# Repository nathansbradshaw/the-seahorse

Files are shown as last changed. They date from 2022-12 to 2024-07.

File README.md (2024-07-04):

# The Seahorse v2 

34 key keyboard with TP

Link to ZMK code https://github.com/nathansbradshaw/zmk-the-seahorse
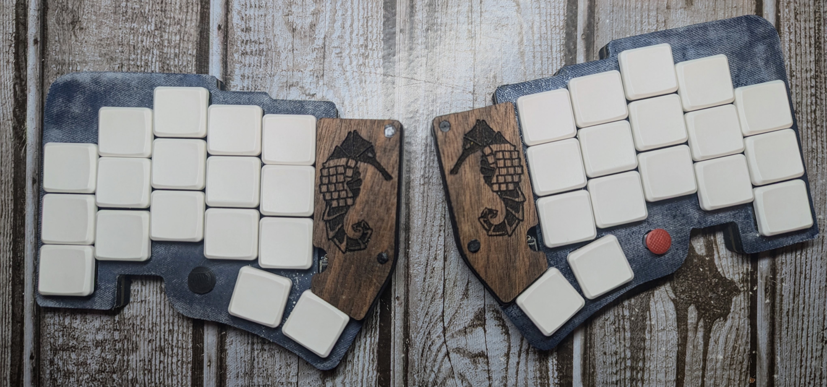
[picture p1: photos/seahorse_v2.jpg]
the-seahorse board


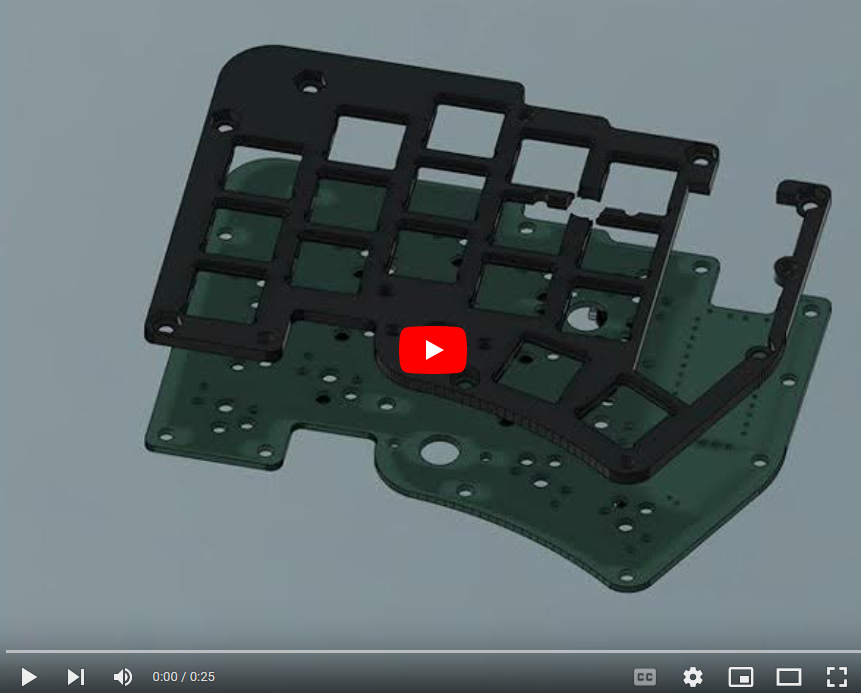
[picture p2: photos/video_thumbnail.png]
IMAGE ALT TEXT (https://www.youtube.com/watch?v=ttfX7KnK4Xc "Video Title")


# BOM
These are links to what I bought, not necessary to get exactly the same

## items
- 4x (12 socket) [2.54mm Sockets (Cheap) - Recommended](https://www.amazon.com/gp/product/B0778TFL39/ref=ppx_yo_dt_b_search_asin_image?ie=UTF8&psc=1) or  [2.54mm Sockets (Quality)](https://www.mouser.com/ProductDetail/Mill-Max/315-43-112-41-003000?qs=s8Nb1z4Wn%2FRfWrVqQ0TOuQ%3D%3D)

- 48x [Mill Max Pins - Recommend (Digikey)](https://www.digikey.com/en/products/detail/3320-0-00-15-00-00-03-0/4147392)

- 34x [Choc Hot Swap Sockets](https://www.boardsource.xyz/products/Choc_Hot_Swap_Sockets)

- 34x Choc Switches

- 34x Choc Key caps

- 2x Nice!Nano or equivalent

- 34x [1N4148W-7-F - Diodes](https://www.digikey.com/en/products/detail/diodes-incorporated/1N4148W-7-F/814371)

- 2x [SSSS811101 - Battery Switch](https://www.digikey.com/en/products/detail/alps-alpine/SSSS811101/19529062?s=N4IgTCBcDaIMoLgDgIxoAwpAXQL5A)

- 2x [PTS636 SL43 LFS - Reset Switch](https://www.digikey.com/en/products/detail/c-k/PTS636-SL43-LFS/10071714)

- 2x [Lithium Battery 110mAh](https://typeractive.xyz/products/lithium-battery-110mah)

- 2x [JST Battery Jack](https://typeractive.xyz/products/battery-jack)

- 1x [T460s - Track Point (12 pin RED version)]()

- 1x [2005280120 - 12 pin 1.0mm Pitch (Note: Link might be wrong)](https://www.digikey.com/en/products/detail/molex/2005280120/12142065?s=N4IgTCBcDa4AxwKxgBwFo4EYxwAQgF0BfIA)

- 2x 1.8m screw and nut

# Estimated Cost to build (Updated July 3, 2024)

|Amount| | Item | Cost |Salvageable|
|----|---|---|---|---|
| 2  | | Reset Switch | $0.20 USD | No  |
| 2  | | Nice!Nano | $50.00 USD  | Yes |
| 2  | | Lithium Battery 110mAh  | $6.00 USD | Yes |
| 2  | | JST Battery Jack | $2.00 USD | No  |
| 2  | | Battery Switch | $2.50 | No  |
| 34 | | Choc Switches | $27.00 USD  | Yes |
| 34 | | Hot Swap Choc Sockets | $5.10 USD | No  |
| 34 | | Choc Key cap | $11.90 USD  | Yes |
| 34 | | Diodes | $5.44 USD | No  |
| 48 | | Mill Max Pins | $4.76 USD | yes-ish|
| 4  | | 2.54mm Sockets | $1.60 USD | No  |
| 1  | | PCB | $10.00 USD  | No  |
| 1  | | Track Point | $10.00 USD  | Yes |
| 1  | | FPC Cable | Free w/ TP  | Yes |
| 1  | | FPC connector | $2.00 USD | Yes |
 
-----

 Total Cost Without TP: **$121.74 USD**

 Total Cost With TP: **$133.77 USD**

---------

 Total Cost to upgrade: **$22.10 USD**

 Total Cost to upgrade with TP: **$24.10 USD**

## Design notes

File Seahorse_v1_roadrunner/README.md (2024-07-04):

# The Seahorse V1 or The RoadRunner
------
This keyboard design works well, but had a couple of issues. The main one was that the micro-controller is too close to the keys, which required the user to shave off some of the key caps to get it all to fit.

In other words, build at your own risk.

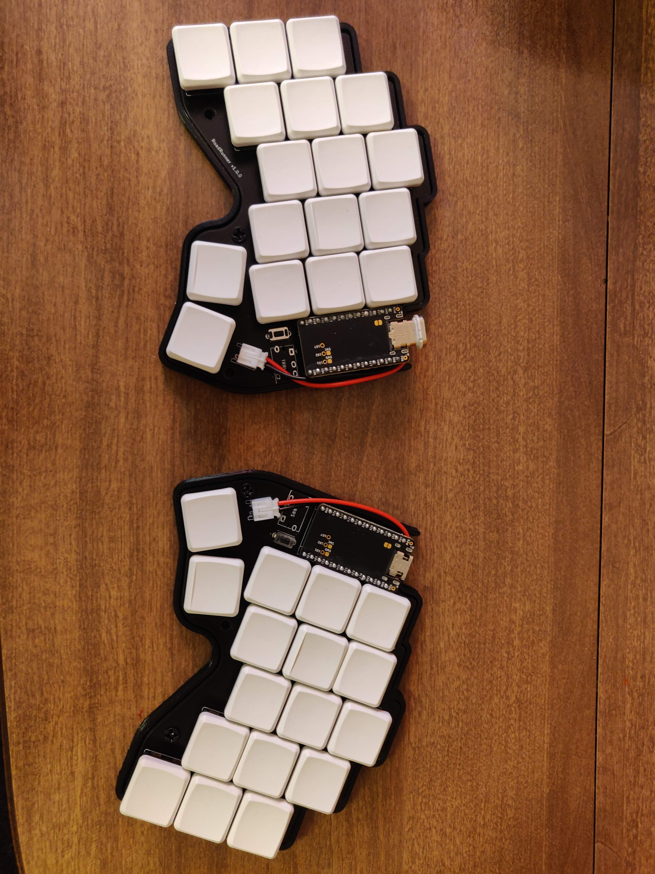
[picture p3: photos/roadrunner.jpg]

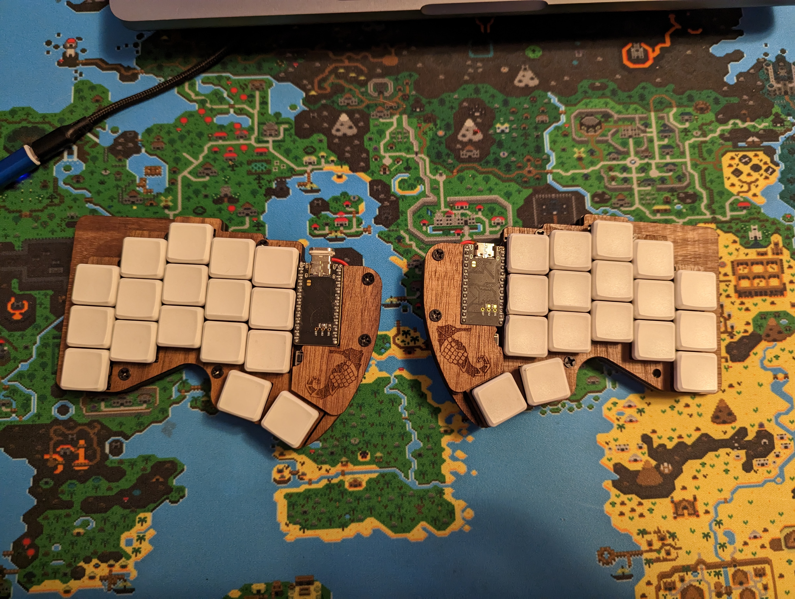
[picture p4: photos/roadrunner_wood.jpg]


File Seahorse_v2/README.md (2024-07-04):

# The Seahorse v2 

34 key keyboard with TP

Link to ZMK code https://github.com/nathansbradshaw/zmk-the-seahorse
the-seahorse board
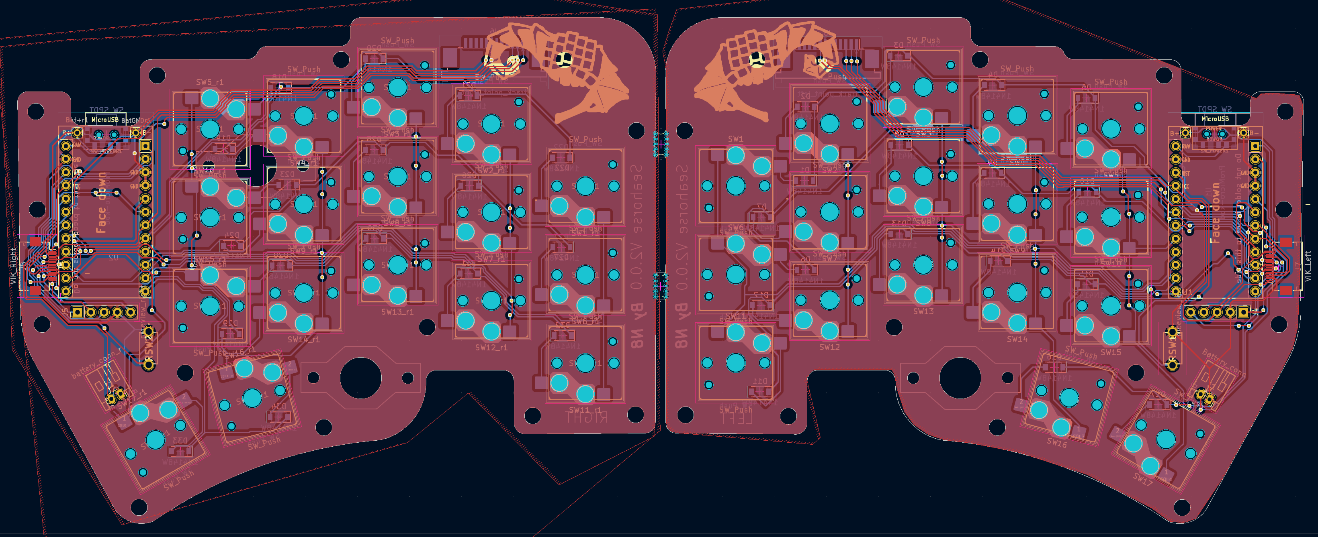
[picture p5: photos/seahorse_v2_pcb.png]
the-seahorse board

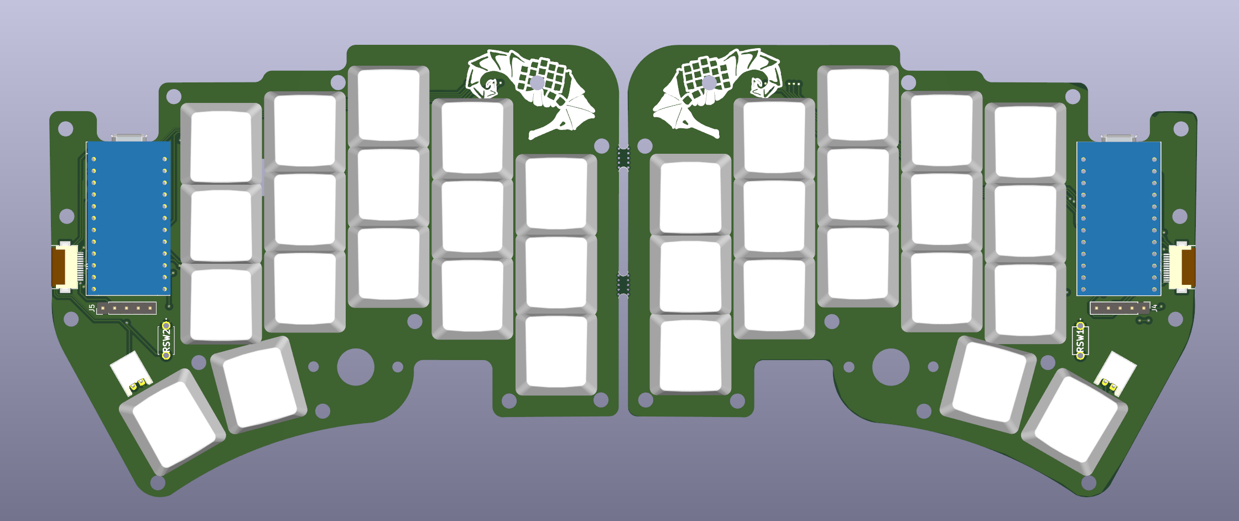
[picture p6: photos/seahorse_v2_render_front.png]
the-seahorse board

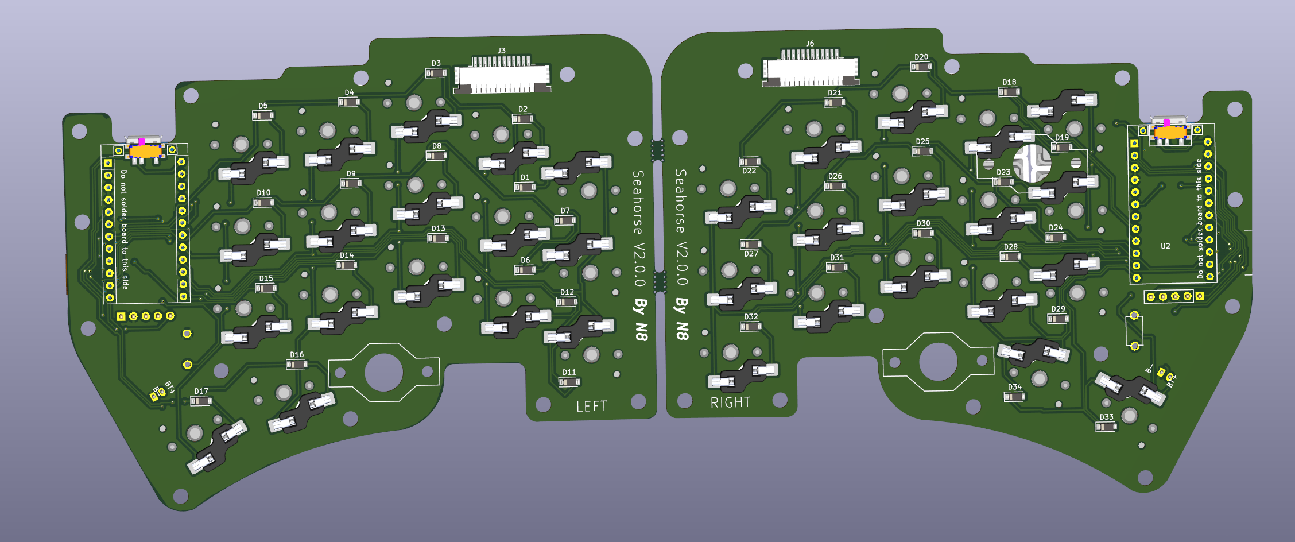
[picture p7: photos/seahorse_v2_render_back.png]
the-seahorse board


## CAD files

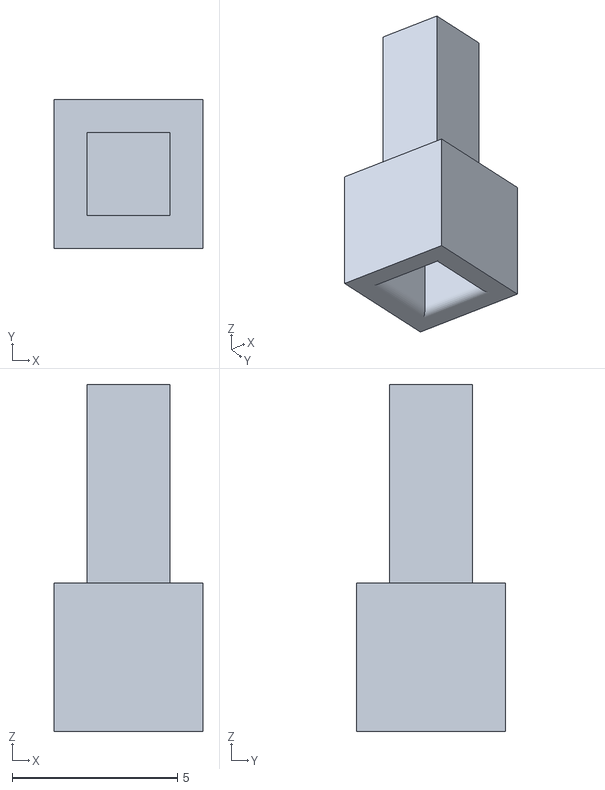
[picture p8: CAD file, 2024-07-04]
print_files/seahorse_v2_files/track_point_extender.stl
4.50 x 4.50 x 10.5

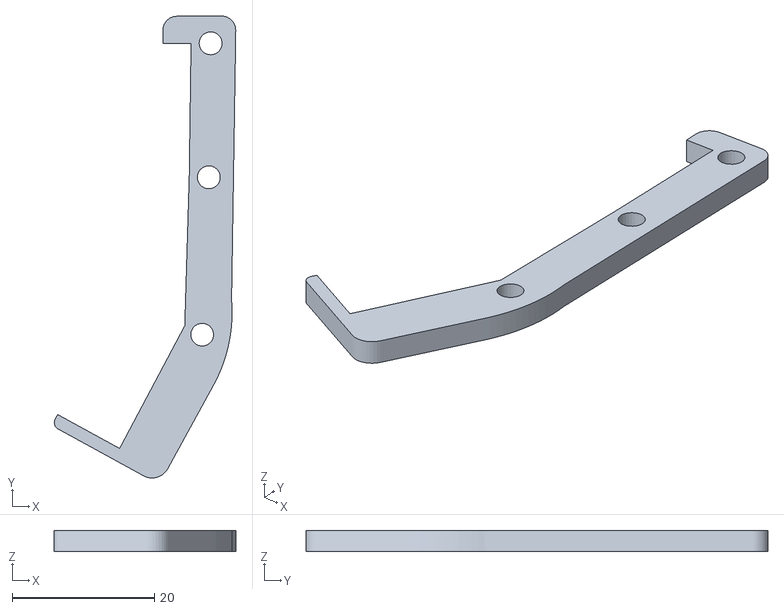
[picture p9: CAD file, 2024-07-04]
print_files/seahorse_v2_files/side_plate_spacer_thick.stl
25.5 x 64.9 x 2.95

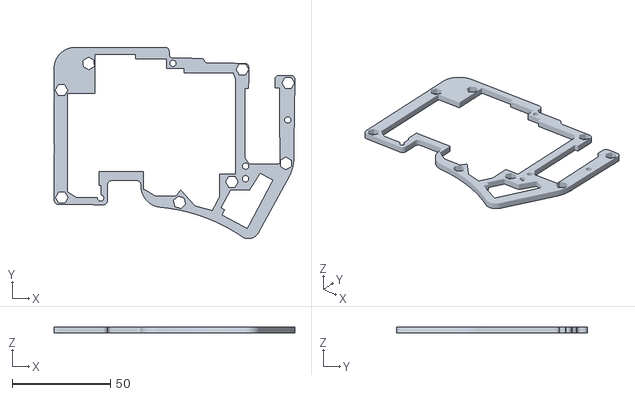
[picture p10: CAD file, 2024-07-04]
print_files/seahorse_v2_files/spacer_plate.stl
122.5 x 97.2 x 3.25

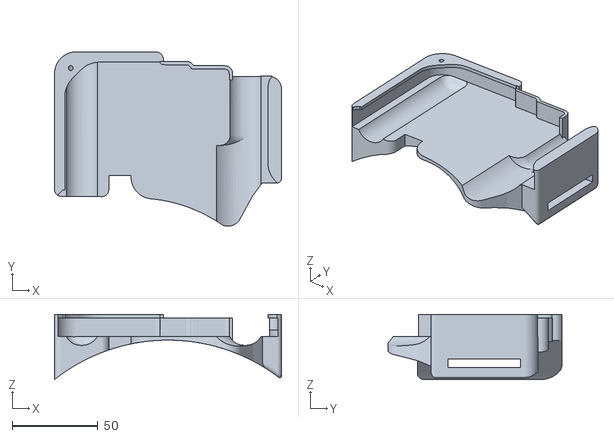
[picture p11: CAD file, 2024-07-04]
print_files/seahorse_v2_files/barnicle.stl
132.5 x 101.8 x 38.0

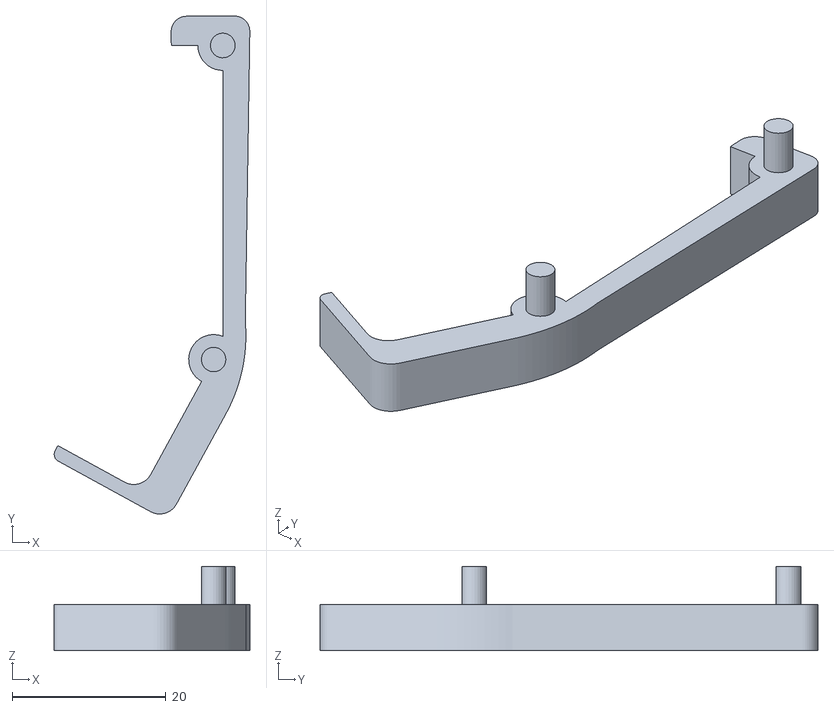
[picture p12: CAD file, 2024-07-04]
print_files/seahorse_v2_files/side_cover_spacer_with_pegs.stl
25.5 x 64.9 x 11.0

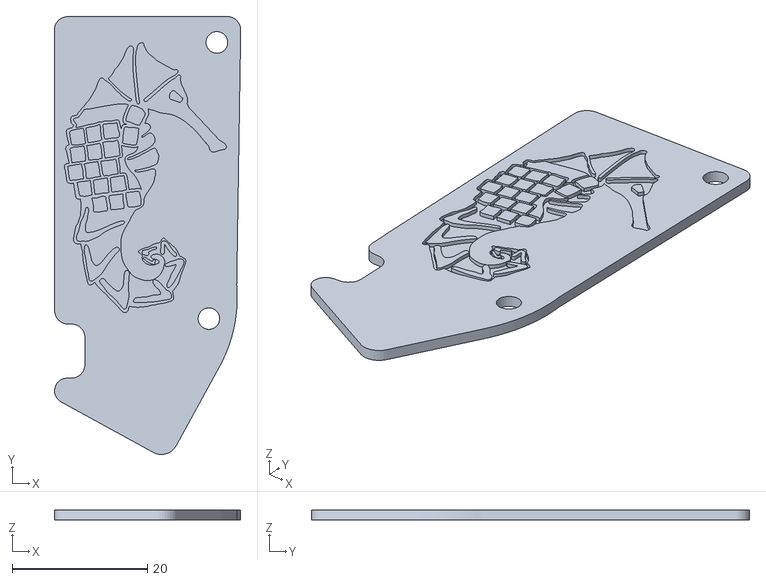
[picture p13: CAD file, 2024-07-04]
print_files/seahorse_v2_files/micro_controller_cover.stl
27.6 x 64.9 x 1.45

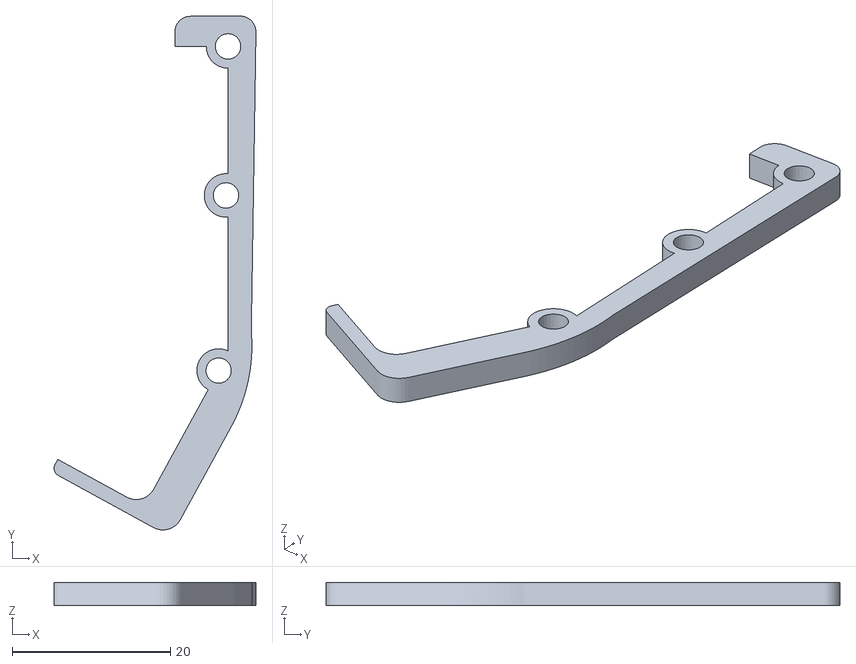
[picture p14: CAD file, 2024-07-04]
print_files/seahorse_v2_files/side_plate_spacer_slim.stl
25.5 x 64.9 x 2.95

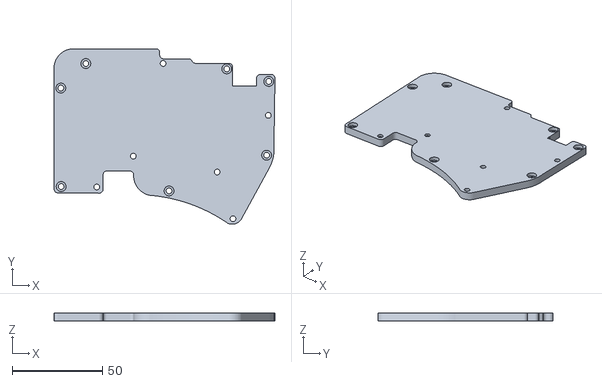
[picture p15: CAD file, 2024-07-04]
print_files/seahorse_v2_files/bottom_print_plate_counter_sink_screw.stl
122.5 x 97.2 x 4.50

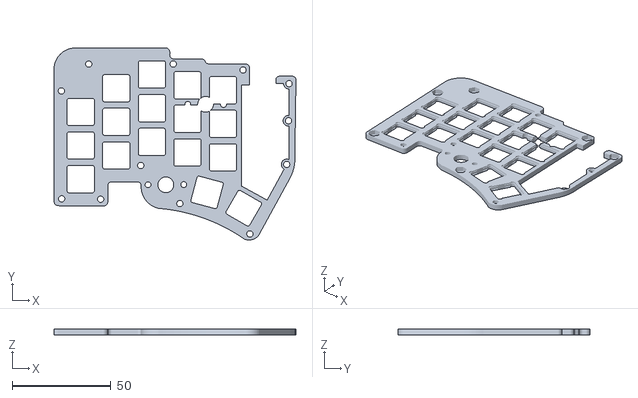
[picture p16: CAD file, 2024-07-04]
print_files/seahorse_v2_files/top_printed_plate_with_nut_holes.stl
122.5 x 97.2 x 2.95

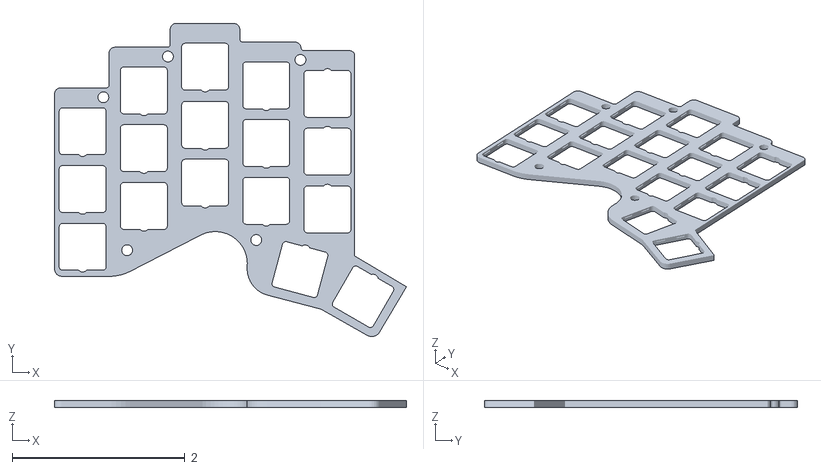
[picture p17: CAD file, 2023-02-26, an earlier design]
print_files/seahorse_v1_files/sea_horse_base_plate_slim_left.stl
4.08 x 3.63 x 0.0787

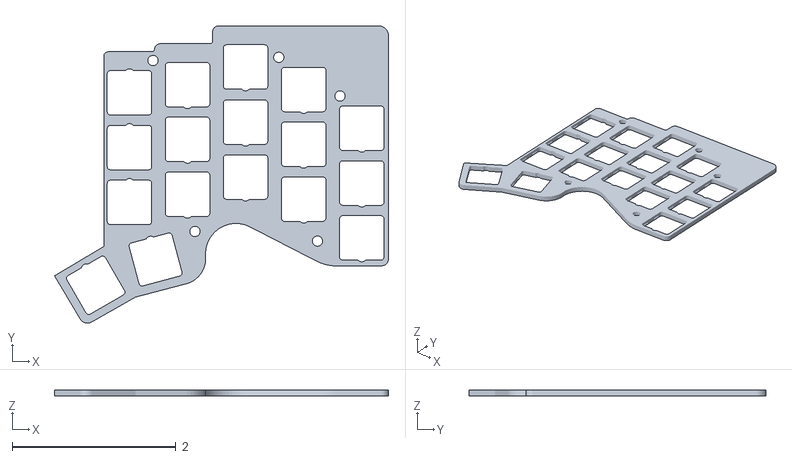
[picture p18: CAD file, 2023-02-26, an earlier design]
print_files/seahorse_v1_files/sea_horse_base_plate_right.stl
4.08 x 3.63 x 0.0787

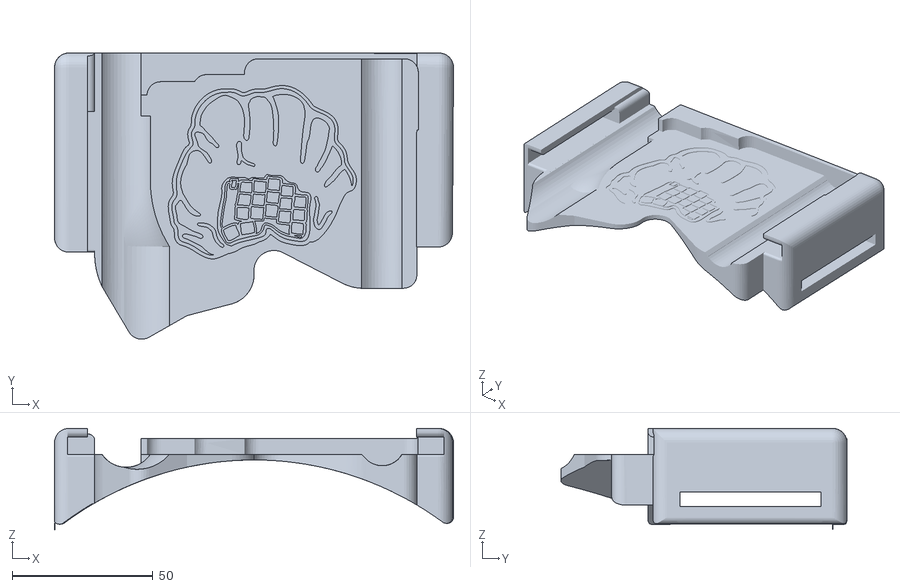
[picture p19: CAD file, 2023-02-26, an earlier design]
print_files/seahorse_v1_files/barnicle-mount v3.stl
141.7 x 101.7 x 35.9

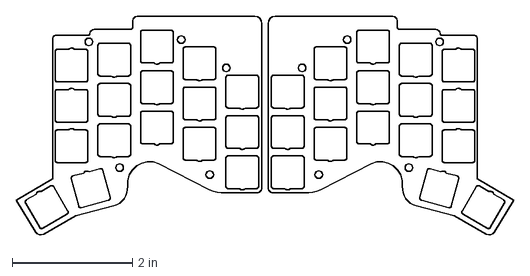
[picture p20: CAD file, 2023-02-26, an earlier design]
print_files/seahorse_v1_files/the_seahorse_base_plate.dxf
8.26 x 3.64 in

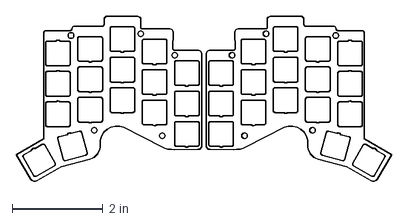
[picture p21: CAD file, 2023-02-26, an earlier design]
print_files/seahorse_v1_files/the_seahorse_base_plate_slim.dxf
8.26 x 3.64 in

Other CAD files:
print_files/seahorse_v1_files/sea_horse_base_plate_slim_righ.stl
print_files/seahorse_v1_files/sea_horse_base_plate_left.stl
print_files/seahorse_v1_files/seahorse-shell v8.stl
print_files/seahorse_v1_files/Barnicle_flat.stl

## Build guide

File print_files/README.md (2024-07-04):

# Print Files

Files that are intended to make the Seahorse easier to use or look at.

[Seahorse V2 Files](./seahorse_v2_files/)

[Seahorse V1 Files (Abandoned)](./seahorse_v1_files/)

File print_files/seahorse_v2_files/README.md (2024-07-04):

# Seahorse V2 Print Files (Experimental)

### Materials
- PLA Filament 
- [M3x8mm flat head Screws](https://www.amazon.com/gp/product/B01N95QH4Y/ref=ppx_yo_dt_b_search_asin_title?ie=UTF8&th=1)
- M3x10mm flat head screws (TODO check this one)
- M3 Nuts
- [M3 H4 threaded insert (Optional)](https://www.amazon.com/gp/product/B0B46YBNV4/ref=ppx_yo_dt_b_search_asin_title?ie=UTF8&psc=1)

For the nuts I ended up buying and designing around this [kit](https://www.amazon.com/gp/product/B08N5XDHMW/ref=ppx_yo_dt_b_search_asin_title?ie=UTF8&psc=1)

Here are the print files I've used to make my keyboard look nice-ish

## STL

---

### Bottom Printed Plate with Screw offsets

[stl file](./bottom_print_plate_counter_sink_screw.stl)

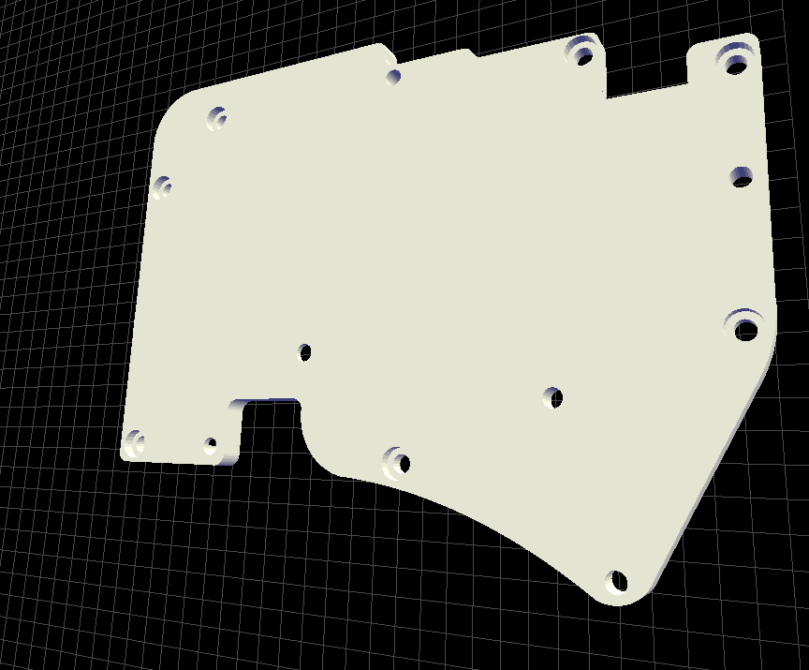
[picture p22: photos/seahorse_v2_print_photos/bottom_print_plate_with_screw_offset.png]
Bottom Printed Plate with Screw Offsets


### Top Printed Plate with nit offsets

[stl file](./top_printed_plate_with_nut_holes.stl)

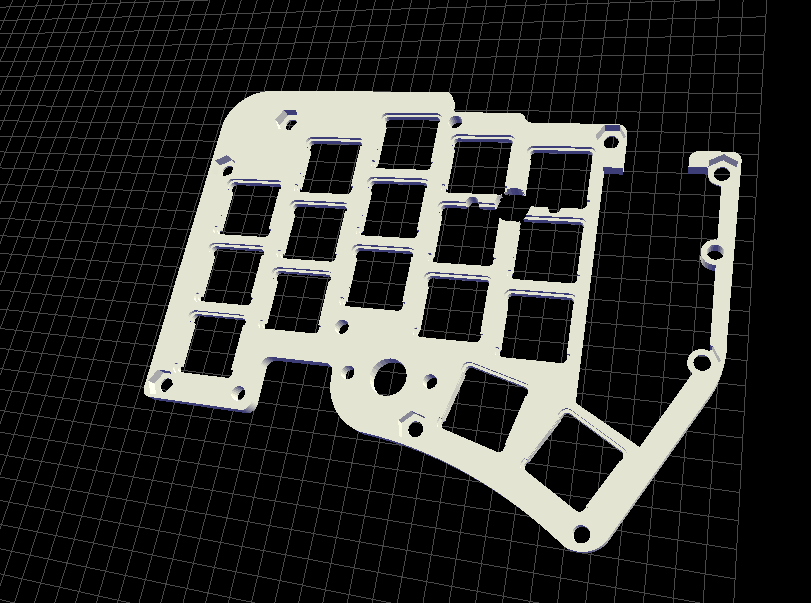
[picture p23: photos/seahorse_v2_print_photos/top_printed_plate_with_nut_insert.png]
Bottom Printed Plate with Screw Offsets


### Micro Controller Cover

[stl file](./micro_controller_cover.stl)

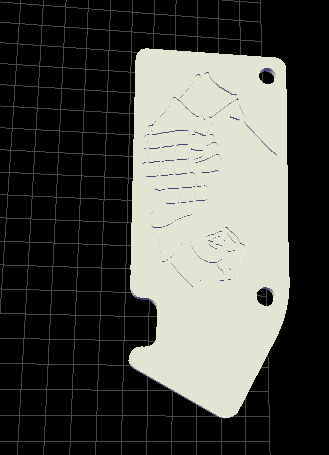
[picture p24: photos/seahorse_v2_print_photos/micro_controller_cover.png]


### Side cover spacer with pegs

[stl file](./side_cover_spacer_with_pegs.stl)

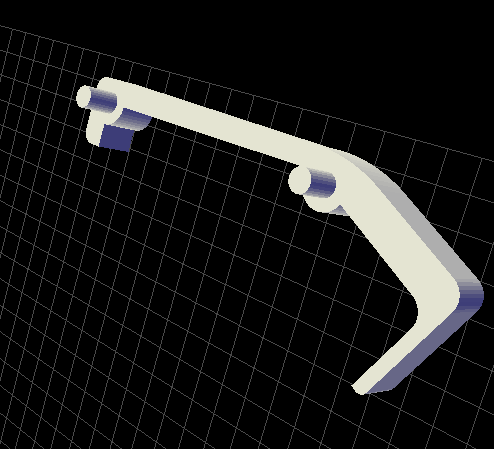
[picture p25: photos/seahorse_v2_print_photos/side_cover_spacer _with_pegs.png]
Bottom Printed Plate with Screw Offsets


### Side cover spacer thin

[stl file](./side_plate_spacer_slim.stl)

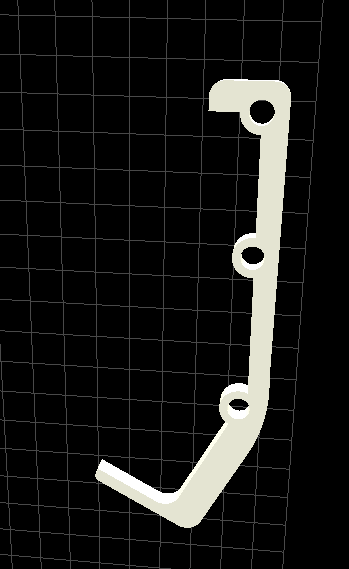
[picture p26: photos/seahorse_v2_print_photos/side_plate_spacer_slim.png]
Bottom Printed Plate with Screw Offsets


### Side cover spacer thick

[stl file](./side_plate_spacer_thick.stl)

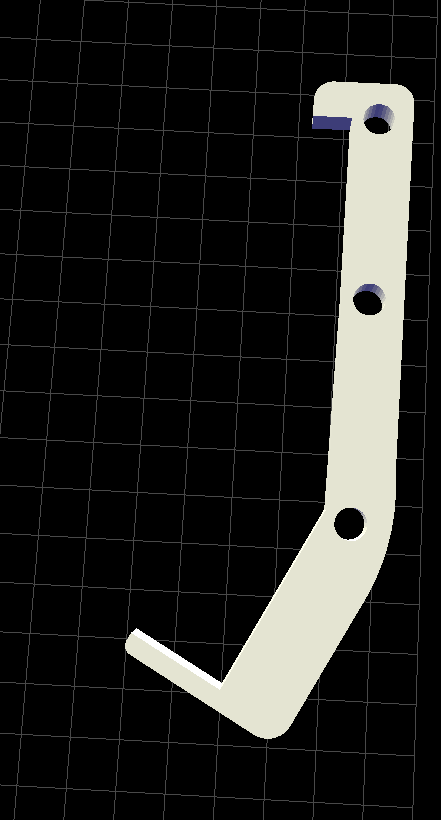
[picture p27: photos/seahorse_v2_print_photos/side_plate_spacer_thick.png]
Bottom Printed Plate with Screw Offsets


### Laser Cut vanity top

[stl file](./updated_vanity_cover.svg)

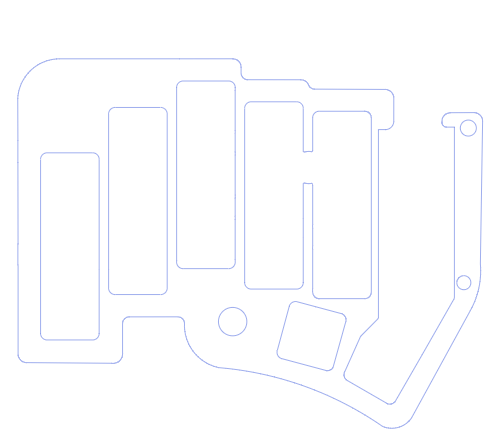
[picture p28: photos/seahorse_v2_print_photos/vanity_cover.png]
Laser Cut vanity top


---
## The Barnacle 

A keyboard mount that you strap to your leg.

Materials:
- PLA Filament 
- Elastic bands
- Buckle

### The Barnacle

[stl file](./barnicle.stl)

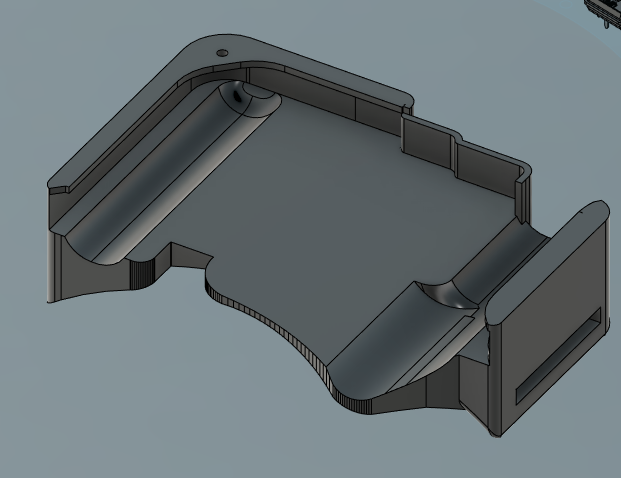
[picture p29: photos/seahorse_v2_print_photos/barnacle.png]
Barnacle


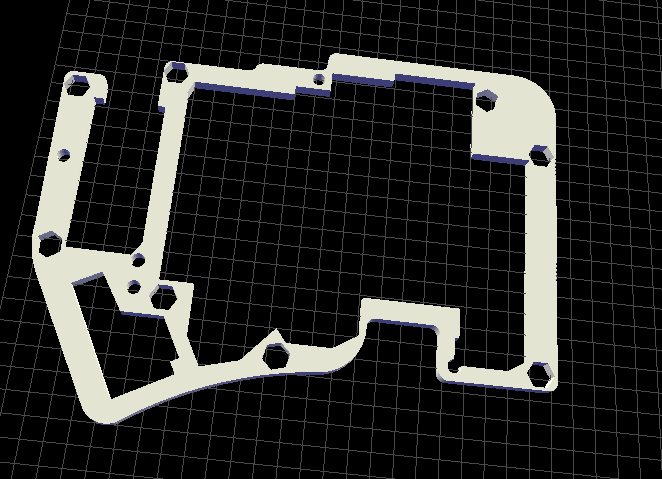
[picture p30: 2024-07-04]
photos/seahorse_v2_print_photos/spacer_plate.png

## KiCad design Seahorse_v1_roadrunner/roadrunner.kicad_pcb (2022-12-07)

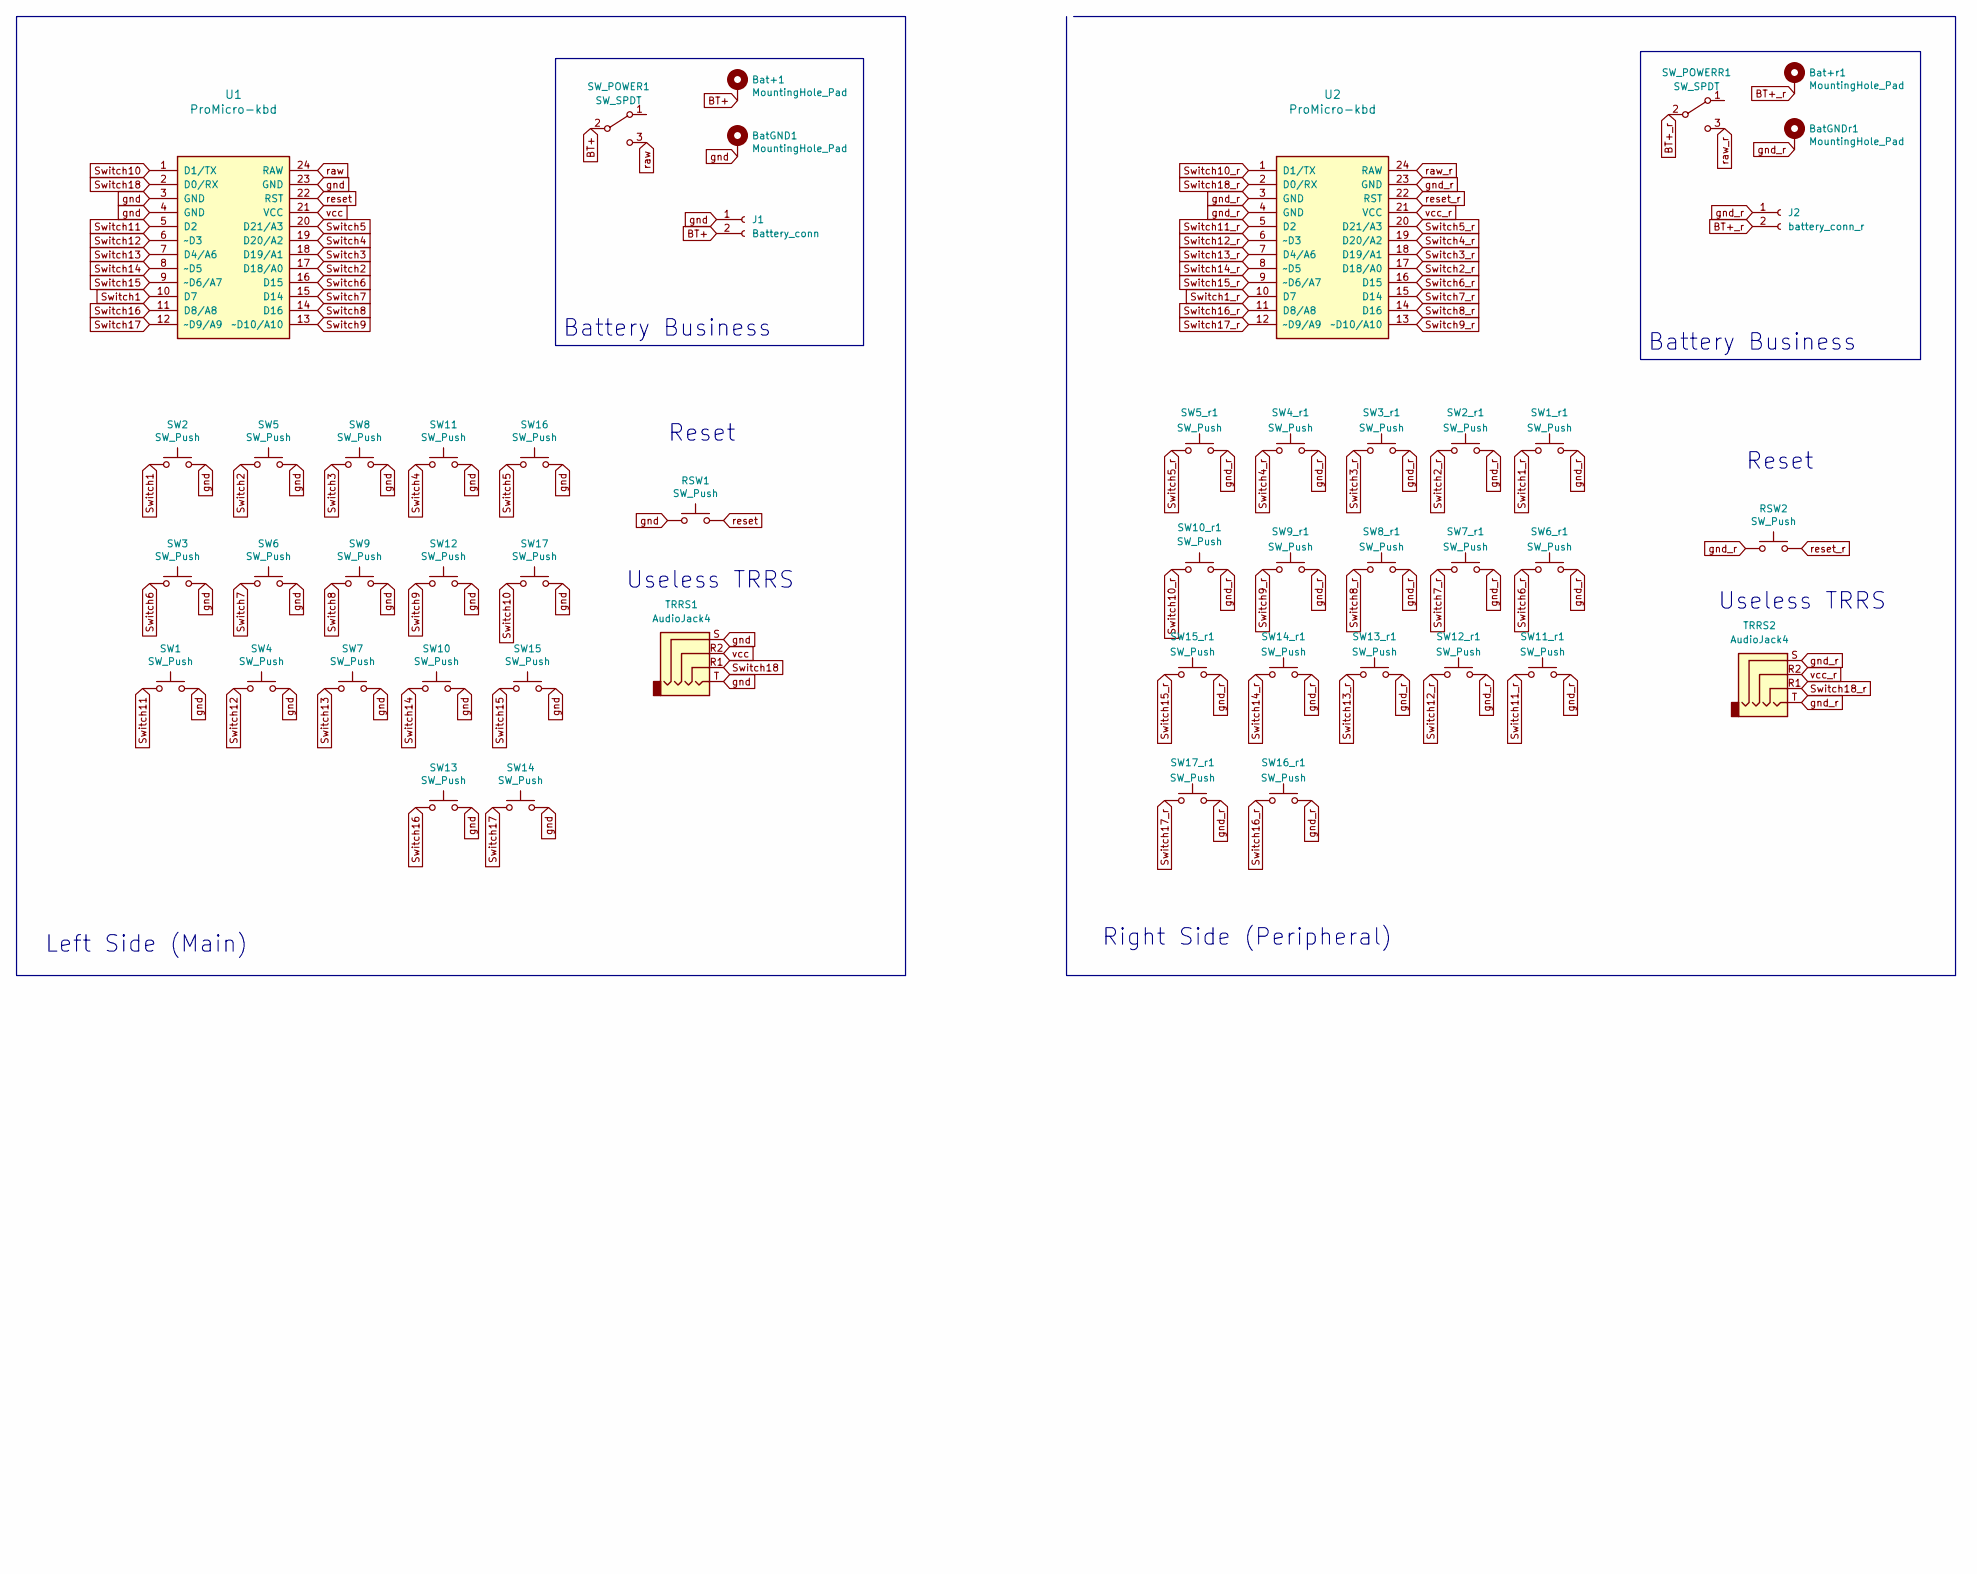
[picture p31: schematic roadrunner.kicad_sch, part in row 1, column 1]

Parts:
Bat+1: MountingHole_Pad; 1pin_conn
Bat+r1: MountingHole_Pad; 1pin_conn
BatGND1: MountingHole_Pad; 1pin_conn
BatGNDr1: MountingHole_Pad; 1pin_conn
J1: Battery_conn; JST_PH_S2B-PH-K_1x02_P2.00mm_Horizontal
J2: battery_conn_r; JST_PH_S2B-PH-K_1x02_P2.00mm_Horizontal
RSW1, RSW2: SW_Push; PTS636SP43LFS
SW1, SW1_r1, SW2, SW2_r1, SW3, SW3_r1, SW4, SW4_r1, SW5, SW5_r1, SW6, SW6_r1, SW7, SW7_r1, SW8, SW8_r1, SW9, SW9_r1, SW10, SW10_r1, SW11, SW11_r1, SW12, SW12_r1, SW13, SW13_r1, SW14, SW14_r1, SW15, SW15_r1, SW16, SW16_r1, SW17, SW17_r1: SW_Push; SW_Hotswap_Kailh_Choc_V1_tweaked
SW_POWER1: SW_SPDT; SPDT_C128955
SW_POWERR1: SW_SPDT; SPDT_C128955
TRRS1, TRRS2: AudioJack4; Jack_3.5mm_PJ320E_Horizontal
U1, U2: ProMicro-kbd; Sparkfun_Pro_Micro

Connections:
BT+: Bat+1.1, J1.2, SW_POWER1.2 (B)
BT+_r: Bat+r1.1, J2.2, SW_POWERR1.2 (B)
Switch1: SW2.1, U1.10 (D7)
Switch1_r: SW1_r1.1, U2.10 (D7)
Switch2: SW5.1, U1.17 (D18/A0)
Switch2_r: SW2_r1.1, U2.17 (D18/A0)
Switch3: SW8.1, U1.18 (D19/A1)
Switch3_r: SW3_r1.1, U2.18 (D19/A1)
Switch4: SW11.1, U1.19 (D20/A2)
Switch4_r: SW4_r1.1, U2.19 (D20/A2)
Switch5: SW16.1, U1.20 (D21/A3)
Switch5_r: SW5_r1.1, U2.20 (D21/A3)
Switch6: SW3.1, U1.16 (D15)
Switch6_r: SW6_r1.1, U2.16 (D15)
Switch7: SW6.1, U1.15 (D14)
Switch7_r: SW7_r1.1, U2.15 (D14)
Switch8: SW9.1, U1.14 (D16)
Switch8_r: SW8_r1.1, U2.14 (D16)
Switch9: SW12.1, U1.13 (~D10/A10)
Switch9_r: SW9_r1.1, U2.13 (~D10/A10)
Switch10: SW17.1, U1.1 (D1/TX)
Switch10_r: SW10_r1.1, U2.1 (D1/TX)
Switch11: SW1.1, U1.5 (D2)
Switch11_r: SW11_r1.1, U2.5 (D2)
Switch12: SW4.1, U1.6 (~D3)
Switch12_r: SW12_r1.1, U2.6 (~D3)
Switch13: SW7.1, U1.7 (D4/A6)
Switch13_r: SW13_r1.1, U2.7 (D4/A6)
Switch14: SW10.1, U1.8 (~D5)
Switch14_r: SW14_r1.1, U2.8 (~D5)
Switch15: SW15.1, U1.9 (~D6/A7)
Switch15_r: SW15_r1.1, U2.9 (~D6/A7)
Switch16: SW13.1, U1.11 (D8/A8)
Switch16_r: SW16_r1.1, U2.11 (D8/A8)
Switch17: SW14.1, U1.12 (~D9/A9)
Switch17_r: SW17_r1.1, U2.12 (~D9/A9)
Switch18: TRRS1.R1, U1.2 (D0/RX)
Switch18_r: TRRS2.R1, U2.2 (D0/RX)
gnd: BatGND1.1, J1.1, RSW1.1, SW1.2, SW2.2, SW3.2, SW4.2, SW5.2, SW6.2, SW7.2, SW8.2, SW9.2, SW10.2, SW11.2, SW12.2, SW13.2, SW14.2, SW15.2, SW16.2, SW17.2, TRRS1.S, TRRS1.T, U1.3 (GND), U1.4 (GND), U1.23 (GND)
gnd_r: BatGNDr1.1, J2.1, RSW2.1, SW1_r1.2, SW2_r1.2, SW3_r1.2, SW4_r1.2, SW5_r1.2, SW6_r1.2, SW7_r1.2, SW8_r1.2, SW9_r1.2, SW10_r1.2, SW11_r1.2, SW12_r1.2, SW13_r1.2, SW14_r1.2, SW15_r1.2, SW16_r1.2, SW17_r1.2, TRRS2.S, TRRS2.T, U2.3 (GND), U2.4 (GND), U2.23 (GND)
raw: SW_POWER1.3 (C), U1.24 (RAW)
raw_r: SW_POWERR1.3 (C), U2.24 (RAW)
reset: RSW1.2, U1.22 (RST)
reset_r: RSW2.2, U2.22 (RST)
vcc: TRRS1.R2, U1.21 (VCC)
vcc_r: TRRS2.R2, U2.21 (VCC)

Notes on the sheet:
Reset
Useless TRRS
Right Side (Peripheral)
Battery Business
Left Side (Main)

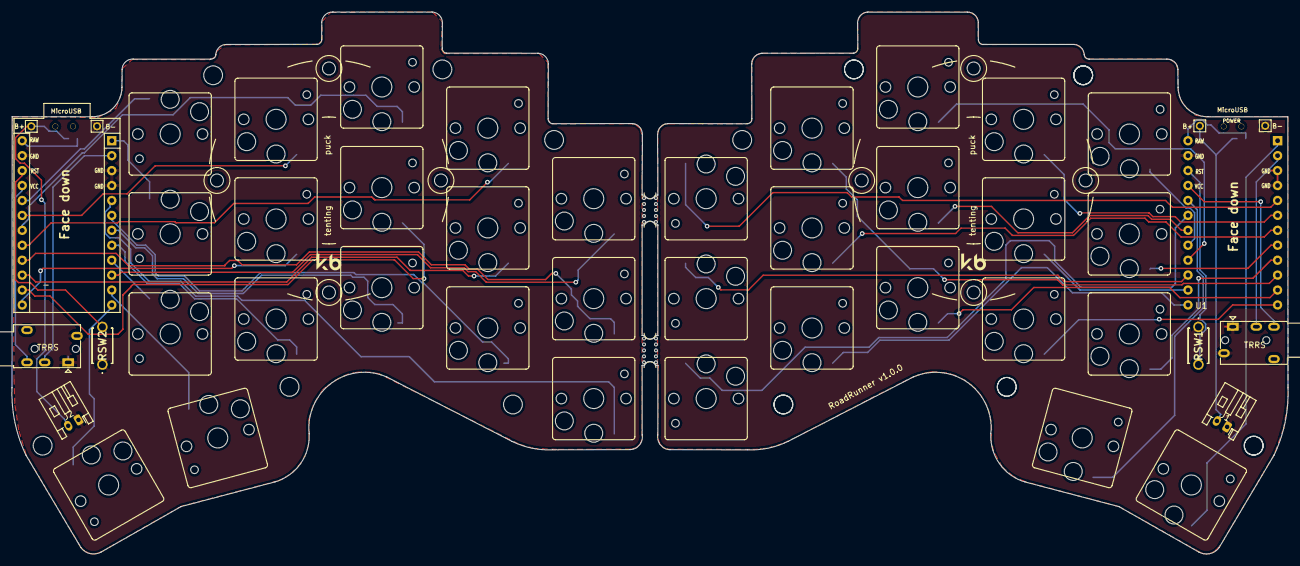
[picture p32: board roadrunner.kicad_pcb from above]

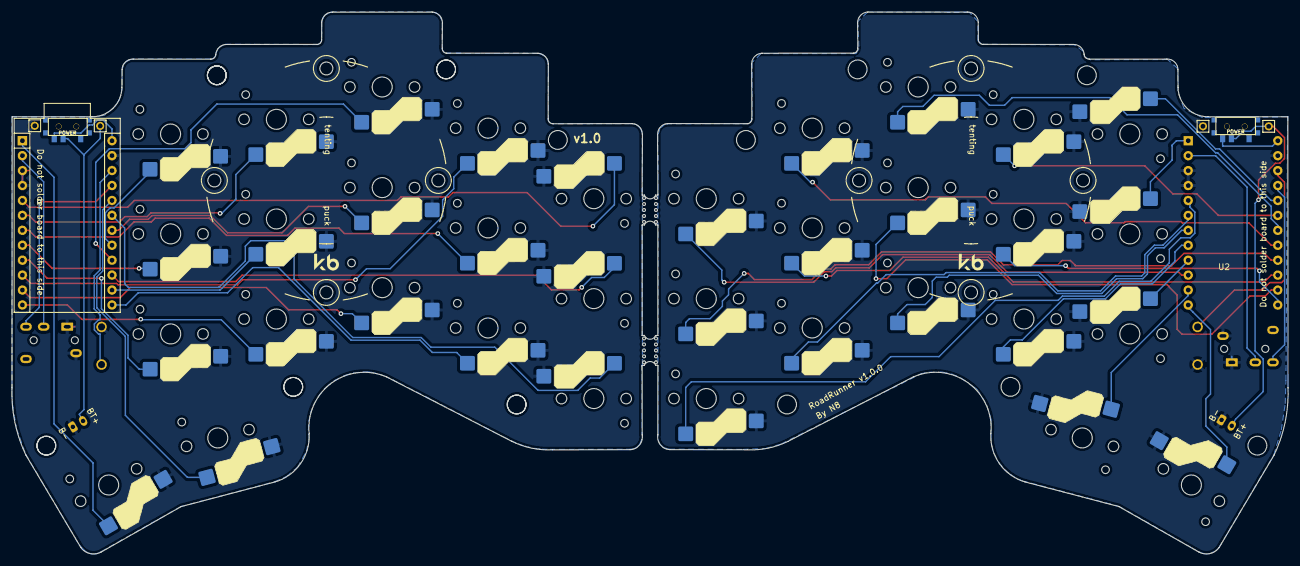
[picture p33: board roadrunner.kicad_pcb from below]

Board: 2 copper layers, 217.1 x 92.2 mm, 52 parts (4 on the bottom side), 46 nets.

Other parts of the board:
REF_PUCK_R: Tenting Puck; Tenting_Puck2_no_pads
e: Tenting Puck; Tenting_Puck2_no_pads
mouse-bite-2mm-slot1, mouse-bite-2mm-slot2: VAL**; mouse-bite-5mm-slot-with-space-for-track

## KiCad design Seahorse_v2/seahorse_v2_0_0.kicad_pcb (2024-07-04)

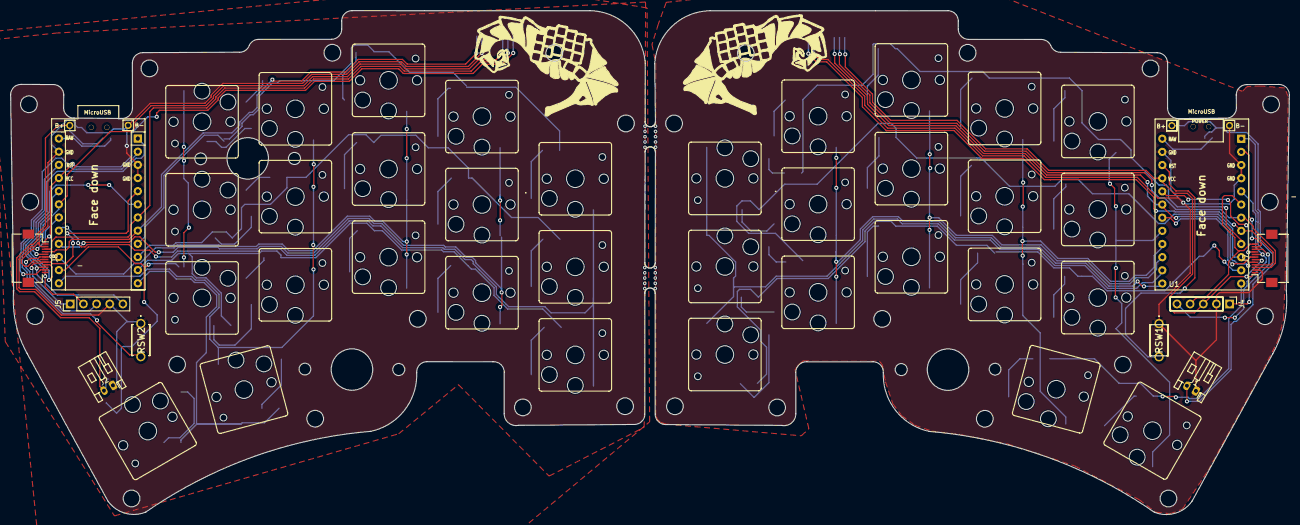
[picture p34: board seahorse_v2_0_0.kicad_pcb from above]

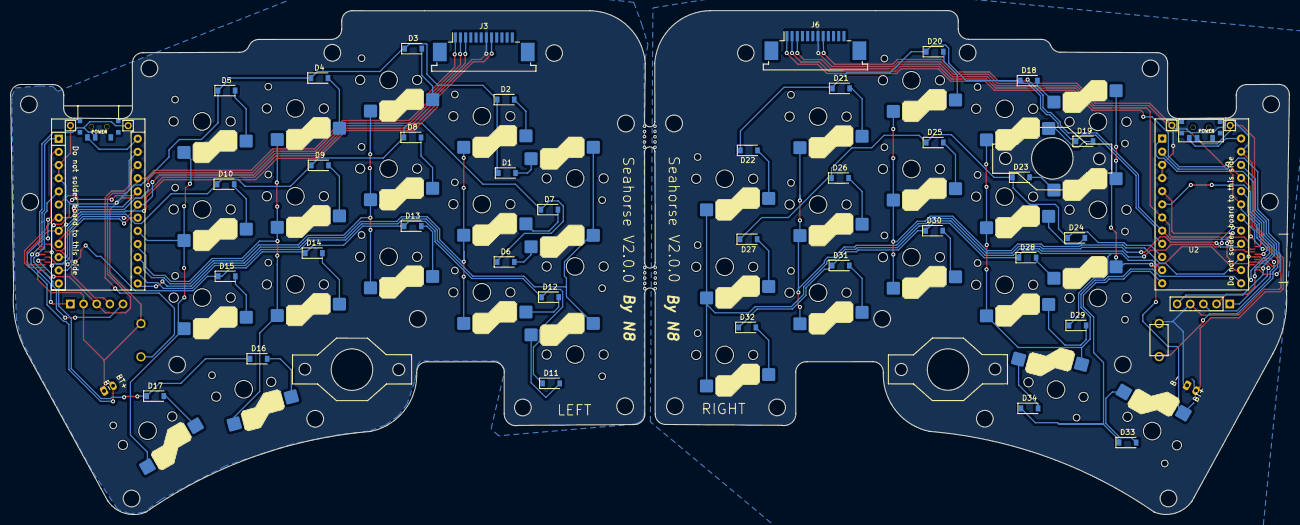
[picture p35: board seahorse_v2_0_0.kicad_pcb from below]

Board: 2 copper layers, 246.8 x 97.3 mm, 88 parts (40 on the bottom side), 80 nets.

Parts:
Bat+1: MountingHole_Pad; 1pin_conn
Bat+r1: MountingHole_Pad; 1pin_conn
BatGND1: MountingHole_Pad; 1pin_conn
BatGNDr1: MountingHole_Pad; 1pin_conn
D1, D2, D3, D4, D5, D6, D7, D8, D9, D10, D11, D12, D13, D14, D15, D16, D17, D18, D19, D20, D21, D22, D23, D24, D25, D26, D27, D28, D29, D30, D31, D32, D33, D34: 1N4148W; D_SOD-123
J1: Battery_conn; JST_PH_S2B-PH-K_1x02_P2.00mm_Horizontal
J2: battery_conn_r; JST_PH_S2B-PH-K_1x02_P2.00mm_Horizontal
J3: track_point_left; TE_1-84953-2_1x12-1MP_P1.0mm_Horizontal
J4: niceview_left; PinHeader_1x05_P2.54mm_Vertical
J5: niceview_right; PinHeader_1x05_P2.54mm_Vertical
J6: track_point_right; TE_1-84953-2_1x12-1MP_P1.0mm_Horizontal
J7: VIK_Left; Hirose_FH12-12S-0.5SH_1x12-1MP_P0.50mm_Horizontal
J8: VIK_Right; Hirose_FH12-12S-0.5SH_1x12-1MP_P0.50mm_Horizontal
RSW1, RSW2: SW_Push; PTS636SP43LFS
SW1, SW1_r1, SW2, SW2_r1, SW3, SW3_r1, SW4, SW4_r1, SW5, SW5_r1, SW6, SW6_r1, SW7, SW7_r1, SW8, SW8_r1, SW9, SW9_r1, SW10, SW10_r1, SW11, SW11_r1, SW12, SW12_r1, SW13, SW13_r1, SW14, SW14_r1, SW15, SW15_r1, SW16, SW16_r1, SW17, SW17_r1: SW_Push; SW_Hotswap_Kailh_Choc_V1_tweaked
SW_POWER1: SW_SPDT; SPDT_C128955
SW_POWERR1: SW_SPDT; SPDT_C128955
U1, U2: ProMicro-kbd; Sparkfun_Pro_Micro
mouse-bite-2mm-slot1, mouse-bite-2mm-slot1#2: VAL**; mouse-bite-5mm-slot-with-space-for-track

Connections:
BT+: Bat+1.1, J1.2, SW_POWER1.2 (B)
BT+_r: Bat+r1.1, J2.2, SW_POWERR1.2 (B)
COL0: SW1.1, SW6.1, SW11.1, U1.14 (D16)
COL0_r: SW5_r1.1, SW10_r1.1, SW15_r1.1, SW17_r1.1, U2.14 (D16)
COL1: SW2.1, SW7.1, SW12.1, U1.13 (~D10/A10)
COL1_r: SW4_r1.1, SW9_r1.1, SW14_r1.1, SW16_r1.1, U2.13 (~D10/A10)
COL2: SW3.1, SW8.1, SW13.1, U1.15 (D14)
COL2_r: SW3_r1.1, SW8_r1.1, SW13_r1.1, U2.15 (D14)
COL3: SW4.1, SW9.1, SW14.1, SW16.1, U1.16 (D15)
COL3_r: SW2_r1.1, SW7_r1.1, SW12_r1.1, U2.16 (D15)
COL4: SW5.1, SW10.1, SW15.1, SW17.1, U1.17 (D18/A0)
COL4_r: SW1_r1.1, SW6_r1.1, SW11_r1.1, U2.17 (D18/A0)
CS: J4.1, J7.10, U1.1 (D1/TX)
CS_r: J5.5, J8.10, U2.1 (D1/TX)
GPIO1: J7.7, U1.18 (D19/A1)
GPIO1_r: J8.7, U2.18 (D19/A1)
GPIO2: J7.9, U1.20 (D21/A3)
GPIO2_r: J8.9, U2.20 (D21/A3)
IPD_CLK: J3.8, J7.4, U1.8 (~D5)
IPD_CLK_r: J6.8, J8.4, U2.8 (~D5)
IPD_DATA: J3.2, J7.3, U1.7 (D4/A6)
IPD_DATA_r: J6.2, J8.3, U2.7 (D4/A6)
IPD_RST: J3.3, J7.5, U1.19 (D20/A2)
IPD_RST_r: J6.3, J8.5, U2.19 (D20/A2)
MISO: J7.11, U1.2 (D0/RX)
MISO_r: J8.11, U2.2 (D0/RX)
MOSI: J4.5, J7.8, U1.5 (D2)
MOSI_r: J5.1, J8.8, U2.5 (D2)
unnamed: D1.2 (A), SW1.2
unnamed: D2.2 (A), SW2.2
unnamed: D3.2 (A), SW3.2
unnamed: D4.2 (A), SW4.2
unnamed: D5.2 (A), SW5.2
unnamed: D6.2 (A), SW6.2
unnamed: D7.2 (A), SW7.2
unnamed: D8.2 (A), SW8.2
unnamed: D9.2 (A), SW9.2
unnamed: D10.2 (A), SW10.2
unnamed: D11.2 (A), SW11.2
unnamed: D12.2 (A), SW12.2
unnamed: D13.2 (A), SW13.2
unnamed: D14.2 (A), SW14.2
unnamed: D15.2 (A), SW15.2
unnamed: D16.2 (A), SW16.2
unnamed: D17.2 (A), SW17.2
unnamed: D18.2 (A), SW5_r1.2
unnamed: D19.2 (A), SW4_r1.2
unnamed: D20.2 (A), SW3_r1.2
unnamed: D21.2 (A), SW2_r1.2
unnamed: D22.2 (A), SW1_r1.2
unnamed: D23.2 (A), SW10_r1.2
unnamed: D24.2 (A), SW9_r1.2
unnamed: D25.2 (A), SW8_r1.2
unnamed: D26.2 (A), SW7_r1.2
unnamed: D27.2 (A), SW6_r1.2
unnamed: D28.2 (A), SW15_r1.2
unnamed: D29.2 (A), SW14_r1.2
unnamed: D30.2 (A), SW13_r1.2
unnamed: D31.2 (A), SW12_r1.2
unnamed: D32.2 (A), SW11_r1.2
unnamed: D33.2 (A), SW17_r1.2
unnamed: D34.2 (A), SW16_r1.2
ROW0: D1.1 (K), D2.1 (K), D3.1 (K), D4.1 (K), D5.1 (K), U1.9 (~D6/A7)
ROW0_r: D18.1 (K), D19.1 (K), D20.1 (K), D21.1 (K), D22.1 (K), U2.9 (~D6/A7)
ROW1: D6.1 (K), D7.1 (K), D8.1 (K), D9.1 (K), D10.1 (K), U1.10 (D7)
ROW1_r: D23.1 (K), D24.1 (K), D25.1 (K), D26.1 (K), D27.1 (K), U2.10 (D7)
ROW2: D11.1 (K), D12.1 (K), D13.1 (K), D14.1 (K), D15.1 (K), U1.11 (D8/A8)
ROW2_r: D28.1 (K), D29.1 (K), D30.1 (K), D31.1 (K), D32.1 (K), U2.11 (D8/A8)
ROW3: D16.1 (K), D17.1 (K), U1.12 (~D9/A9)
ROW3_r: D33.1 (K), D34.1 (K), U2.12 (~D9/A9)
SCK: J4.4, J7.12, U1.6 (~D3)
SCK_r: J5.2, J8.12, U2.6 (~D3)
gnd: BatGND1.1, J1.1, J3.7, J4.2, J7.2, RSW1.1, U1.3 (GND), U1.4 (GND), U1.23 (GND)
gnd_r: BatGNDr1.1, J2.1, J5.4, J6.7, J8.2, RSW2.1, U2.3 (GND), U2.4 (GND), U2.23 (GND)
raw: SW_POWER1.3 (C), U1.24 (RAW)
raw_r: SW_POWERR1.3 (C), U2.24 (RAW)
reset: RSW1.2, U1.22 (RST)
reset_r: RSW2.2, U2.22 (RST)
vcc: J3.1, J4.3, J7.1, J7.6, U1.21 (VCC)
vcc_r: J5.3, J6.1, J8.1, J8.6, U2.21 (VCC)

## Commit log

2022-12-04 update schematic
    [roadrunner.kicad_pcb, roadrunner.kicad_sch]
2022-12-05 update shape
    [roadrunner.kicad_pcb, roadrunner.kicad_sch]
2022-12-07 prepare board for order
    [roadrunner-B_Cu.gbr, roadrunner-B_Mask.gbr, roadrunner-B_Paste.gbr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]
2023-02-26 add print files
    [Barnicle_flat.stl, barnicle-mount v3.stl, sea_horse_base_plate_left.stl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]
2023-10-15 basic v2 designs
    [roadrunner.kicad_pcb, roadrunner.kicad_sch]
2023-10-15 move button
    [roadrunner.kicad_pcb]
2023-10-16 begin adding diodes
    [roadrunner.kicad_pcb, roadrunner.kicad_sch]
2023-10-16 place diodes
    [roadrunner.kicad_pcb, roadrunner.kicad_sch]
2023-10-25 begin adding mouse
    [roadrunner.kicad_pcb, roadrunner.kicad_sch]
2024-02-18 feat: add vik
    [roadrunner.kicad_pcb, roadrunner.kicad_sch]
2024-02-19 update thumbpoint layout
    [roadrunner.kicad_pcb]
2024-02-22 feat: begin routing
    [roadrunner.kicad_pcb]
2024-02-23 add traces
    [roadrunner.kicad_pcb]
2024-02-24 feat: finish wiring v2
    [roadrunner-B_Cu.gbr, roadrunner-B_Mask.gbr, roadrunner-B_Paste.gbr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]
2024-02-24 chore: specify trackpoint model
    [roadrunner.kicad_pcb, roadrunner.kicad_sch]
2024-03-17 feat: make track-point connector reversible
    [roadrunner.kicad_sch]
2024-07-04 feat: update readme
    [Barnicle_flat.stl, barnicle-mount v3.stl, sea_horse_base_plate_left.stl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]
2024-07-04 chore: clean up files
    [roadrunner-B_Cu.gbr, roadrunner-B_Mask.gbr, roadrunner-B_Paste.gbr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]
2024-07-04 feat: add print files
    [barnicle.stl, bottom_print_plate_counter_sink_screw.stl, micro_controller_cover.stl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]
2024-07-04 chore: add print files readme
2024-07-04 feat: add track point extender stl
    [track_point_extender.stl]
